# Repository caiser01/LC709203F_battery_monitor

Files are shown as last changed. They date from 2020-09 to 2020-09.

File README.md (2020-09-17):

# LC709203F LiPo Fuel Gauge #

The ON Semiconductor LC709203F Battery Fuel Gauge is an IC for monitoring the charge state of a single lithium ion cell. The IC communicates over an I2C bus and provides the battery's relative state-of-charge (RSOC) and voltage. The LC709203F can also determine battery temperature if an optional external thermistor is attached to the battery. It can also provide an alarm output signal if the battery charge or voltage is below a threshold set by the user.

More information is available from ON Semiconductor:
[LC709203F: Battery Fuel Gauge for 1-Cell Lithium-Ion/Polymer](https://www.onsemi.com/products/power-management/battery-management/battery-fuel-gauges/lc709203f)

## Respository Contents ##
* **/Firmware** - Arduino example and driver
* **/Hardware** - Eagle PCB files for a simple test board

### Software Used ###

* EAGLE 7.7
* Arduino 1.8.5

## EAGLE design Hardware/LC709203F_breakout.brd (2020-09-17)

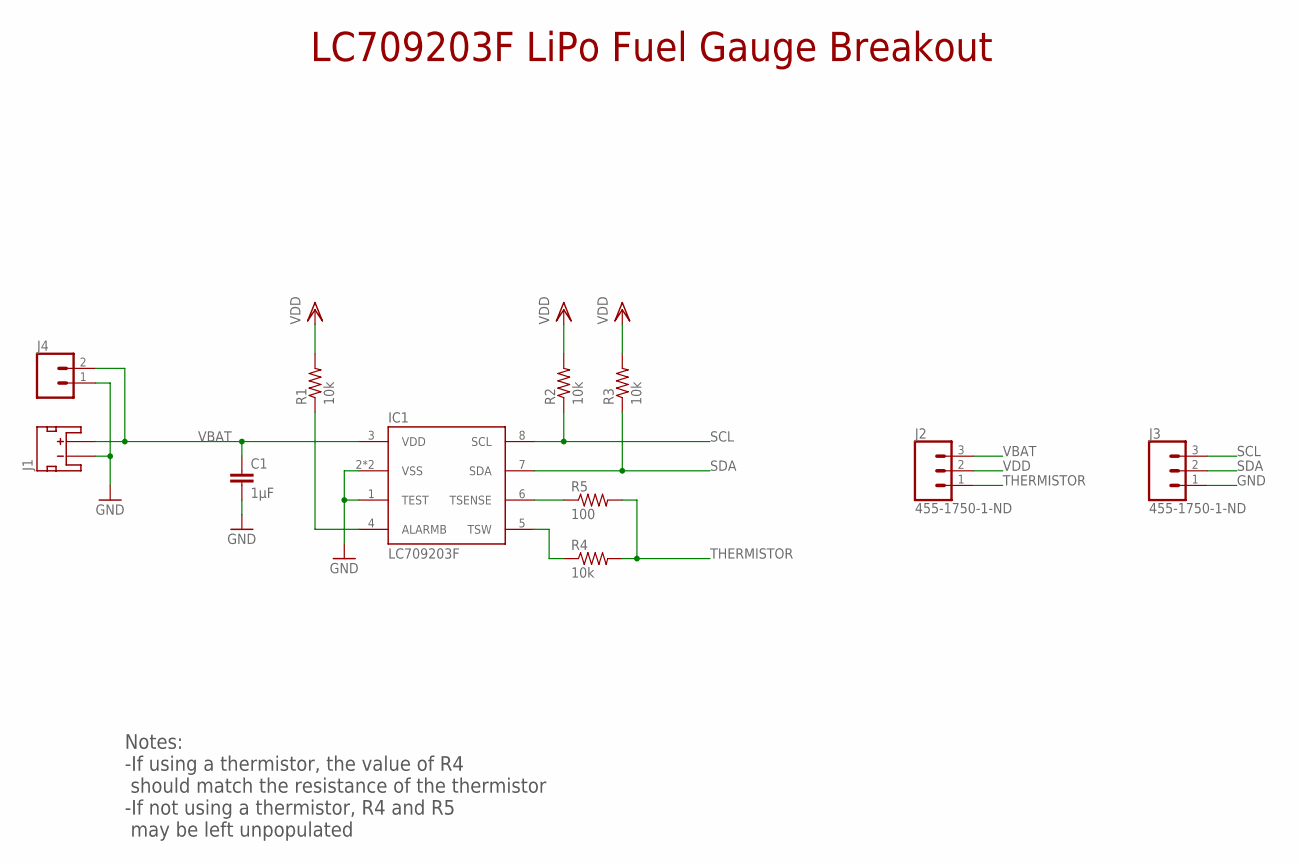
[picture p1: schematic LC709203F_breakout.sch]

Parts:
C1: 1µF; C0805
IC1: LC709203F; WDFN8_ONSEMI
J1: S2B-PH-SM4-TB; JST-2-SMD
J2, J3: 455-1750-1-ND; 1X03
J4: CONN_02; 1X02
R1, R2, R3, R4: 10k; R0805
R5: 100; R0805

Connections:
GND: C1.2, IC1.1 (TEST), IC1.2 (VSS), IC1.9 (VSS), J1.1 (-), J3.1, J4.1
unnamed: IC1.4 (ALARMB), R1.1
unnamed: IC1.6 (TSENSE), R5.1
unnamed: IC1.5 (TSW), R4.1
SCL: IC1.8 (SCL), J3.3, R2.1
SDA: IC1.7 (SDA), J3.2, R3.1
THERMISTOR: J2.1, R4.2, R5.2
VBAT: C1.1, IC1.3 (VDD), J1.2 (+), J2.3, J4.2
VDD: J2.2, R1.2, R2.2, R3.2

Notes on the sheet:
LC709203F LiPo Fuel Gauge Breakout
Notes: -If using a thermistor, the value of R4 should match the resistance of the thermistor -If not using a thermistor, R4 and R5 may be left unpopulated

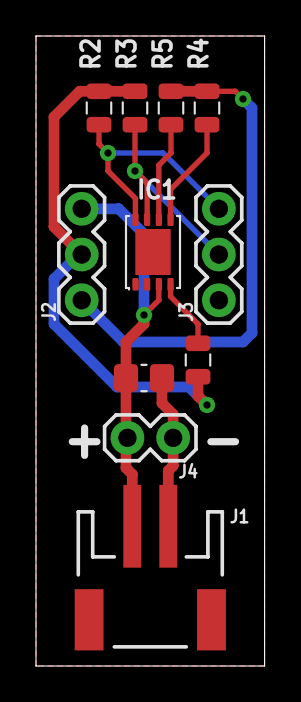
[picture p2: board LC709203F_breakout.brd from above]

Board: 4 copper layers, 12.7 x 35.0 mm, 11 parts (0 on the bottom side), 9 nets.

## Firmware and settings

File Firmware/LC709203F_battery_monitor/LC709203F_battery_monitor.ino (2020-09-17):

#include <Wire.h>
#include "LC709203F.h"

// commResult.registerData contains raw data read from or
// written to the chip
// For a read, commResult.commStatus indicates whether 
// a valid CRC was received or not
// For a write commResult.commStatus indicates whether
// the input data was within range of valid data for
// the given register
LC709203F::I2C_Comms commResult;

// An object for communicating with the LC709203F IC
LC709203F batteryMonitor;

void setup() {
  Serial.begin(9600);
  Wire.begin();

  // LC709203F initialization
  
  // APA value must be determined from the data given in
  // Figure 12, Table 7, and Table 8 in the datasheet.
  // The value below is for a typical 2000mAh LiPo battery
  batteryMonitor.setAPA(0x2D);

  // Battery profile depends on battery capacity. See Table 8.
  batteryMonitor.setBatteryProfile(0);

  // Temperature is set by I2C
  batteryMonitor.setStatusBit(I2C_MODE);

  // Set initial temperature to 20 degrees C
  batteryMonitor.setCellTemperature(TEMPERATURE_OFFSET + 200);
}

void loop() {

  // Read and display some basic stats about the battery
  
  commResult = batteryMonitor.getCellTemperature();
  // Temperature reading is in 0.1 degree Celsius increments
  // Divide by 10 to get whole degrees
  float battTemp = (commResult.registerData - TEMPERATURE_OFFSET) / 10.0;

  commResult = batteryMonitor.getCellVoltage();
  int battVolt = commResult.registerData;

  commResult = batteryMonitor.getRSOC();
  int RSOC = commResult.registerData;
  
  Serial.println("Battery stats");
  
  Serial.print("Cell Temperature (degC): ");
  Serial.println(battTemp);
  
  Serial.print("Cell Voltage (mV): ");
  Serial.println(battVolt);
  
  Serial.print("State of charge (%): ");
  Serial.println(RSOC);
  
  Serial.println();
  
  delay(1000);
}

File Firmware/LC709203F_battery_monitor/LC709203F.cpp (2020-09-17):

/**************************************************************************
 *                                                                         *
 * LC709203F* Driver for Arduino                                           *
 *                                                                         *
 * Christopher A. Isert                                                    *
 *                                                                         *
 ***************************************************************************/

#include "LC709203F.h"

void LC709203F::initRSOCsampledvoltage(){
  simpleWrite(LC709203F_BEFORE_RSOC, INIT_RSOC);
}

LC709203F::I2C_Comms LC709203F::getThermistorB(){
  return simpleRead(LC709203F_THERMISTOR_B);
}

LC709203F::I2C_Comms LC709203F::setThermistorB(int thermistor_const){
  return simpleWrite(LC709203F_THERMISTOR_B, thermistor_const);
}

void LC709203F::initRSOC(){
  simpleWrite(LC709203F_INITIAL_RSOC, INIT_RSOC);
}

LC709203F::I2C_Comms LC709203F::getCellTemperature(){
  return simpleRead(LC709203F_CELL_TEMPERATURE);
}

LC709203F::I2C_Comms LC709203F::setCellTemperature(int cellTemp){
  if ((cellTemp >= 0x09E4) && (cellTemp <= 0x0D04)){
    return simpleWrite(LC709203F_CELL_TEMPERATURE, cellTemp);
  }
  else {
    LC709203F::I2C_Comms commWrite;
    commWrite.registerData = cellTemp;
    commWrite.commStatus = false;
    return commWrite;
  }
}

LC709203F::I2C_Comms LC709203F::getCellVoltage(){
  return simpleRead(LC709203F_CELL_VOLTAGE);
}

LC709203F::I2C_Comms LC709203F::getCurrentDirection(){
  return simpleRead(LC709203F_CURRENT_DIRECTION);
}

LC709203F::I2C_Comms LC709203F::setCurrentDirection(int currDir){
  return simpleWrite(LC709203F_CURRENT_DIRECTION, currDir);
}

LC709203F::I2C_Comms LC709203F::getAPA(){
  return simpleRead(LC709203F_APA);
}

LC709203F::I2C_Comms LC709203F::setAPA(int APA){
  if ((APA >= 0) && (APA <= 0x00FF)){
    return simpleWrite(LC709203F_APA, APA);
  }
  else {
    LC709203F::I2C_Comms commWrite;
    commWrite.registerData = APA;
    commWrite.commStatus = false;
    return commWrite;
  }  
}

LC709203F::I2C_Comms LC709203F::getAPT(){
  return simpleRead(LC709203F_APT);
}

LC709203F::I2C_Comms LC709203F::setAPT(int APT){
  return simpleWrite(LC709203F_APT, APT);
}

LC709203F::I2C_Comms LC709203F::getRSOC(){
  return simpleRead(LC709203F_RSOC);
}

LC709203F::I2C_Comms LC709203F::getITE(){
  return simpleRead(LC709203F_ITE);
}

LC709203F::I2C_Comms LC709203F::getICVersion(){
  return simpleRead(LC709203F_IC_VERSION);
}

LC709203F::I2C_Comms LC709203F::getBatteryProfile(){
  return simpleRead(LC709203F_CHANGE_OF_PARAM);
}

LC709203F::I2C_Comms LC709203F::setBatteryProfile(int battProf){
  return simpleWrite(LC709203F_CHANGE_OF_PARAM, battProf);
}

LC709203F::I2C_Comms LC709203F::getAlarmLowRSOC(){
  return simpleRead(LC709203F_ALARM_LOW_RSOC);
}

LC709203F::I2C_Comms LC709203F::setAlarmLowRSOC(int lowRSOCthresh){
  if ((lowRSOCthresh >= 0) && (lowRSOCthresh <= 0x0064)){
    return simpleWrite(LC709203F_ALARM_LOW_RSOC, lowRSOCthresh);
  }
  else {
    LC709203F::I2C_Comms commWrite;
    commWrite.registerData = lowRSOCthresh;
    commWrite.commStatus = false;
    return commWrite;
  }  
}

LC709203F::I2C_Comms LC709203F::getAlarmLowCellVoltage(){
  return simpleRead(LC709203F_ALARM_LOW_CELL_VOLTAGE);
}

LC709203F::I2C_Comms LC709203F::setAlarmLowCellVoltage(int lowCellVoltThresh){
  return simpleWrite(LC709203F_ALARM_LOW_CELL_VOLTAGE, lowCellVoltThresh);
}

LC709203F::I2C_Comms LC709203F::getICPowerMode(){
  return simpleRead(LC709203F_IC_POWER_MODE);
}

LC709203F::I2C_Comms LC709203F::setICPowerMode(int powerMode){
  return simpleWrite(LC709203F_IC_POWER_MODE, powerMode);
}

LC709203F::I2C_Comms LC709203F::getStatusBit(){
  return simpleRead(LC709203F_STATUS_BIT);
}

LC709203F::I2C_Comms LC709203F::setStatusBit(int statusBit){
  return simpleWrite(LC709203F_STATUS_BIT, statusBit);
}

LC709203F::I2C_Comms LC709203F::getNumberofParam(){
  return simpleRead(LC709203F_NUMBER_OF_PARAM);
}

LC709203F::I2C_Comms LC709203F::simpleWrite(unsigned char commandCode, int dataToWrite){
  LC709203F::I2C_Comms commWrite;
  commWrite.registerData = dataToWrite;
  writeRegister(commandCode, commWrite);
  commWrite.commStatus = true;
  return commWrite;
}

LC709203F::I2C_Comms LC709203F::simpleRead(unsigned char commandCode){
  LC709203F::I2C_Comms commRead;  
  readRegister(commandCode, commRead);  
  return commRead;
}

void LC709203F::writeRegister(unsigned char commandCode, LC709203F::I2C_Comms commWrite){
  unsigned char dataByteLow = (unsigned char)(0x00FF & commWrite.registerData);
  unsigned char dataByteHigh = (unsigned char)((0xFF00 & commWrite.registerData) >> 8);

  // Calculate CRC, chip will not accept data without a valid CRC
  unsigned char message[LC709203F_WRITE_LENGTH] = {LC709203F_WRITE_ADDR, commandCode, dataByteLow, dataByteHigh};
  unsigned char crc = calcCRC8(message, LC709203F_WRITE_LENGTH - 1);

  // Write register data and CRC
  Wire.beginTransmission(LC709203F_ADDRESS);
  Wire.write(commandCode);
  //Wire.write(commWrite.registerData);
  Wire.write(dataByteLow);
  Wire.write(dataByteHigh);
  Wire.write(crc);
  Wire.endTransmission();

  commWrite.commStatus = 0;
}

void LC709203F::readRegister(unsigned char commandCode, LC709203F::I2C_Comms &commRead){
  // Send the command code
  Wire.beginTransmission(LC709203F_ADDRESS);
  Wire.write(commandCode);
  Wire.endTransmission(false); // false because the chip requires a repeated start

  // Receive the register data and CRC
  Wire.requestFrom(LC709203F_ADDRESS, LC709203F_RESPONSE_LENGTH);
  
  unsigned char dataByteLow = Wire.read();
  unsigned char dataByteHigh = Wire.read();

  // Combine upper and lower data bytes
  commRead.registerData = 0xFF00 & (dataByteHigh << 8);
  commRead.registerData |= 0x00FF & dataByteLow;
  
  unsigned char crc = Wire.read();
  
  unsigned char message[LC709203F_READ_LENGTH] = {LC709203F_WRITE_ADDR, commandCode, LC709203F_READ_ADDR, dataByteLow, dataByteHigh, crc};
  crc = calcCRC8(message, LC709203F_READ_LENGTH);

  // True only if CRC is good
  commRead.commStatus = (crc == 0);
}

// https://chromium.googlesource.com/chromiumos/platform/vboot_reference/+/664096bd1a7247b751bf4e564738d53a1e2795c2/firmware/lib/crc8.c

/**
 * Return CRC-8 of the data, using x^8 + x^2 + x + 1 polynomial.  A table-based
 * algorithm would be faster, but for only a few bytes it isn't worth the code
 * size. */
unsigned char LC709203F::calcCRC8(const unsigned char *vptr, int len)
{
  const unsigned char *data = vptr;
  unsigned int crc = 0;
  int i, j;
  for (j = len; j; j--, data++) {
    crc ^= (*data << 8);
    for(i = 8; i; i--) {
      if (crc & 0x8000)
        crc ^= (0x1070 << 3);
      crc <<= 1;
    }
  }
  return (unsigned char)(crc >> 8);
}

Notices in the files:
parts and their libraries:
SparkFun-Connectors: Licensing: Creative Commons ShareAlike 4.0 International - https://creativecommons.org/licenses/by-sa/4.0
